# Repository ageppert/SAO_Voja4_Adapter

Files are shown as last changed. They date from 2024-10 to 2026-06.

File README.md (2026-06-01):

# SAO VOJA4 BADGE ADAPTER

Hardware add-on to enable Voja4 to speak I2C with a full-featured 6-pin SAO socket.

Maybe even SPI!

Follow this project at: https://hackaday.io/project/198394-sao-adapter-for-voja4-badge

Hardware Version 1.0 Prototype

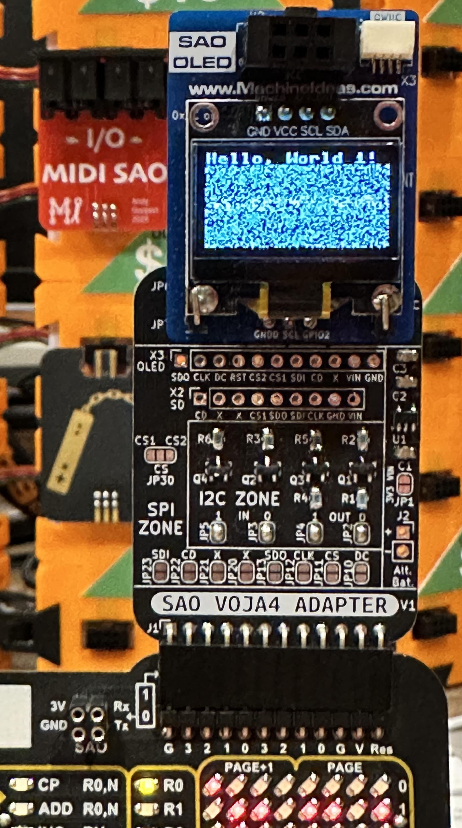
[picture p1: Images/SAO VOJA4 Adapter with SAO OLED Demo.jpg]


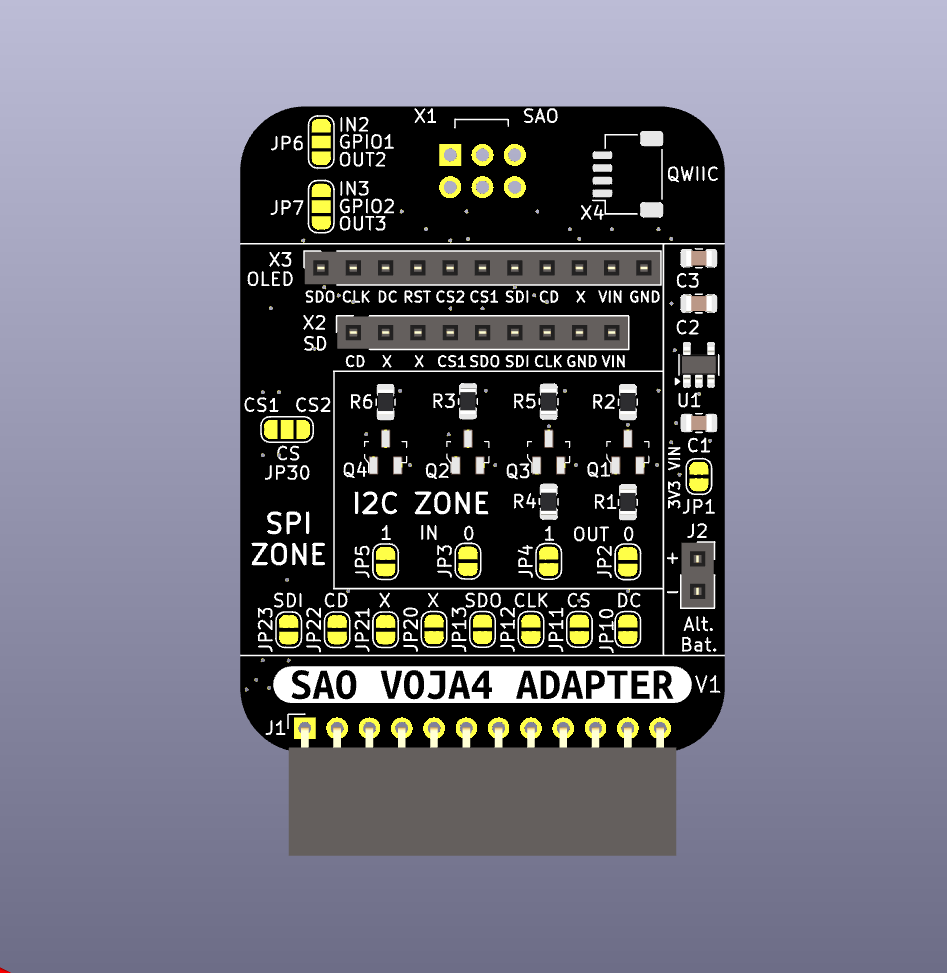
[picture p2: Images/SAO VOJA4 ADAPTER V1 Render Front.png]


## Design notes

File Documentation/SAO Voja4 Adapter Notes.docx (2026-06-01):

SAO Voja4 Adapter Notes V1.0

Kit Components

REF. DES. | DESCRIPTION | COMPONENT
C1, C3 | Capacitor, 1uF
C2 | Capacitor, 0.01uF
J1 | BYOB Battery 2.5-5.5 V
J2 | 0.1 inch female edge connect, 12-position
Q1-4 | Transistor, NPN, MMBT4401LT1G
R1, R4 | Resistor, 0805, 470 Ohm
R2,R3,R5,R6 | Resistor, 0805, 3K3 Ohm
U1 | LDO Regulator 3V3, SSP9193-33MSR
X1 | SAO Socket, Sullins SFH11-NBPC-D03-ST-BK, female, keyed
X2 | Any 0.1 inch pitch female header, 9-pin
X3 | Any 0.1 inch pitch female header, 11-pin
X4 | QWIIC Socket, 4-pos, male, keyed

Configuration Table

FEATURE | JP1 | JP2,4 | JP3,5 | JP6,7 | Q4 | JP10-13 | JP20-21 | JP22-23 | JP30 | Blue Wire Q4 Base to JP30 pad 3
I2C | ~ | Close | Close | ~ | In | Open | ~ | Open | Open | ~
SPI, Single | ~ | ~ | Open | Open | ~ | Close | ~ | Close | Close 1-2 | ~
SPI, Double * | ~ | Close | Open | Open | Out | Close | ~ | Close | Close 1-2 | Close
Alternate Power ** | Close | ~ | ~ | ~ | ~ | ~ | ~ | ~ | ~ | ~

* Dual SPI mode uses a single OUT1 line to toggle both CS1 and CS2 lines, with opposite logic.

OUT1 | CS1 | CS2
LOW | LOW | LOW
HIGH | HIGH | HIGH

** If using Alternate Power, limit alternate power voltage between 2.5 and 5.5V, and remove the batteries from the Voja4 Badge. This feature may be used with any of the other configuration features.

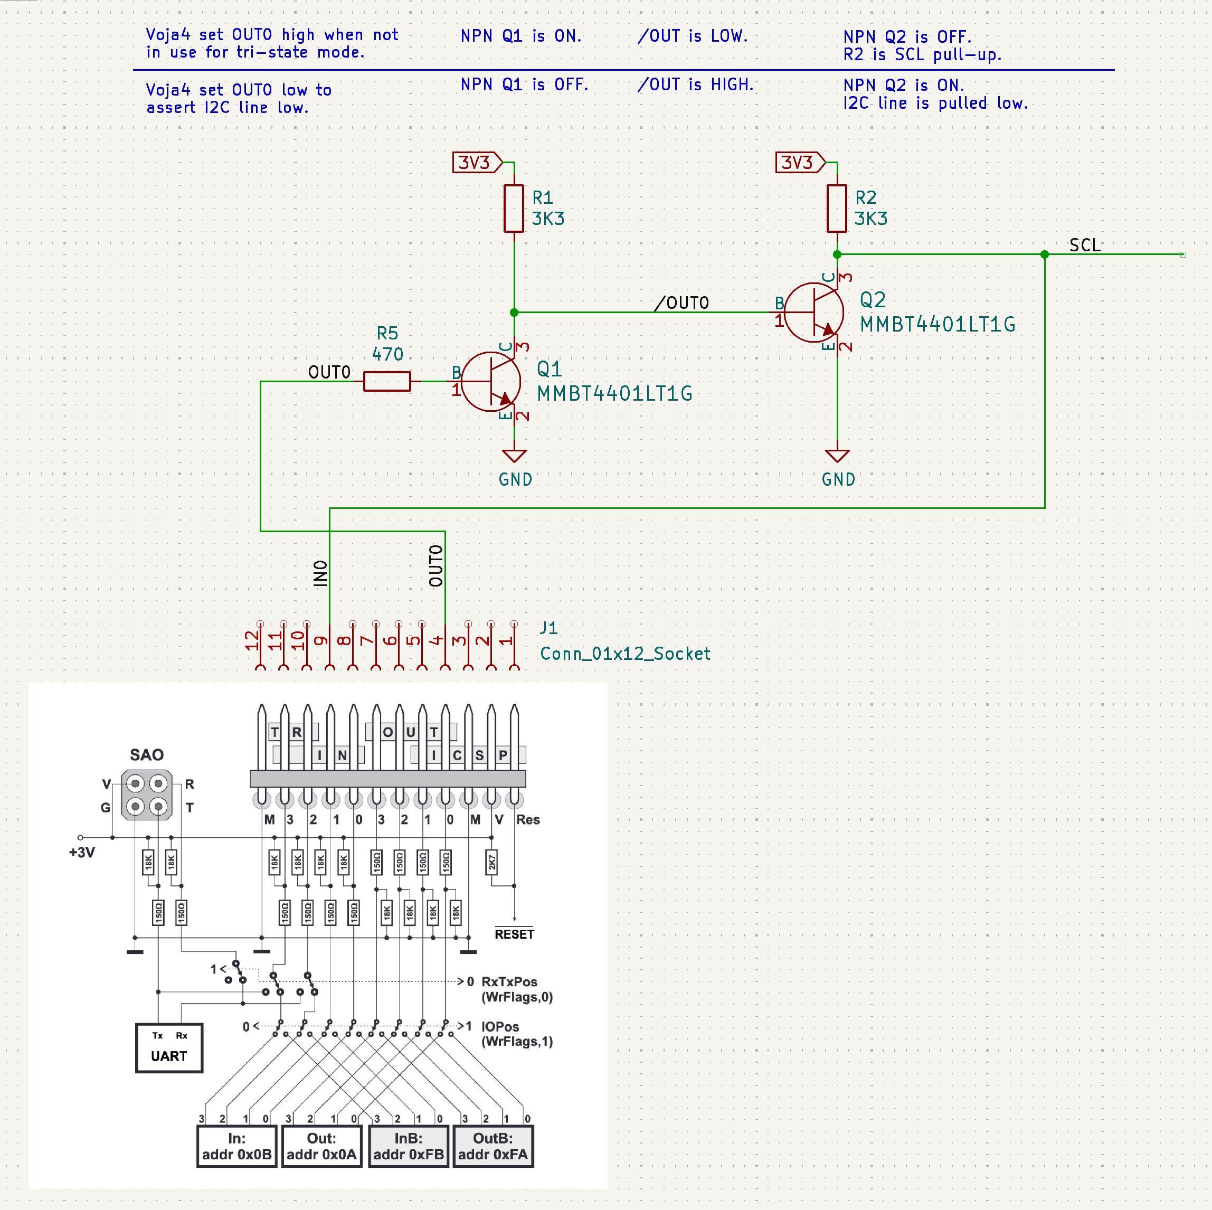
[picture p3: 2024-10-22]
Images/Schematic concept double NOT.png

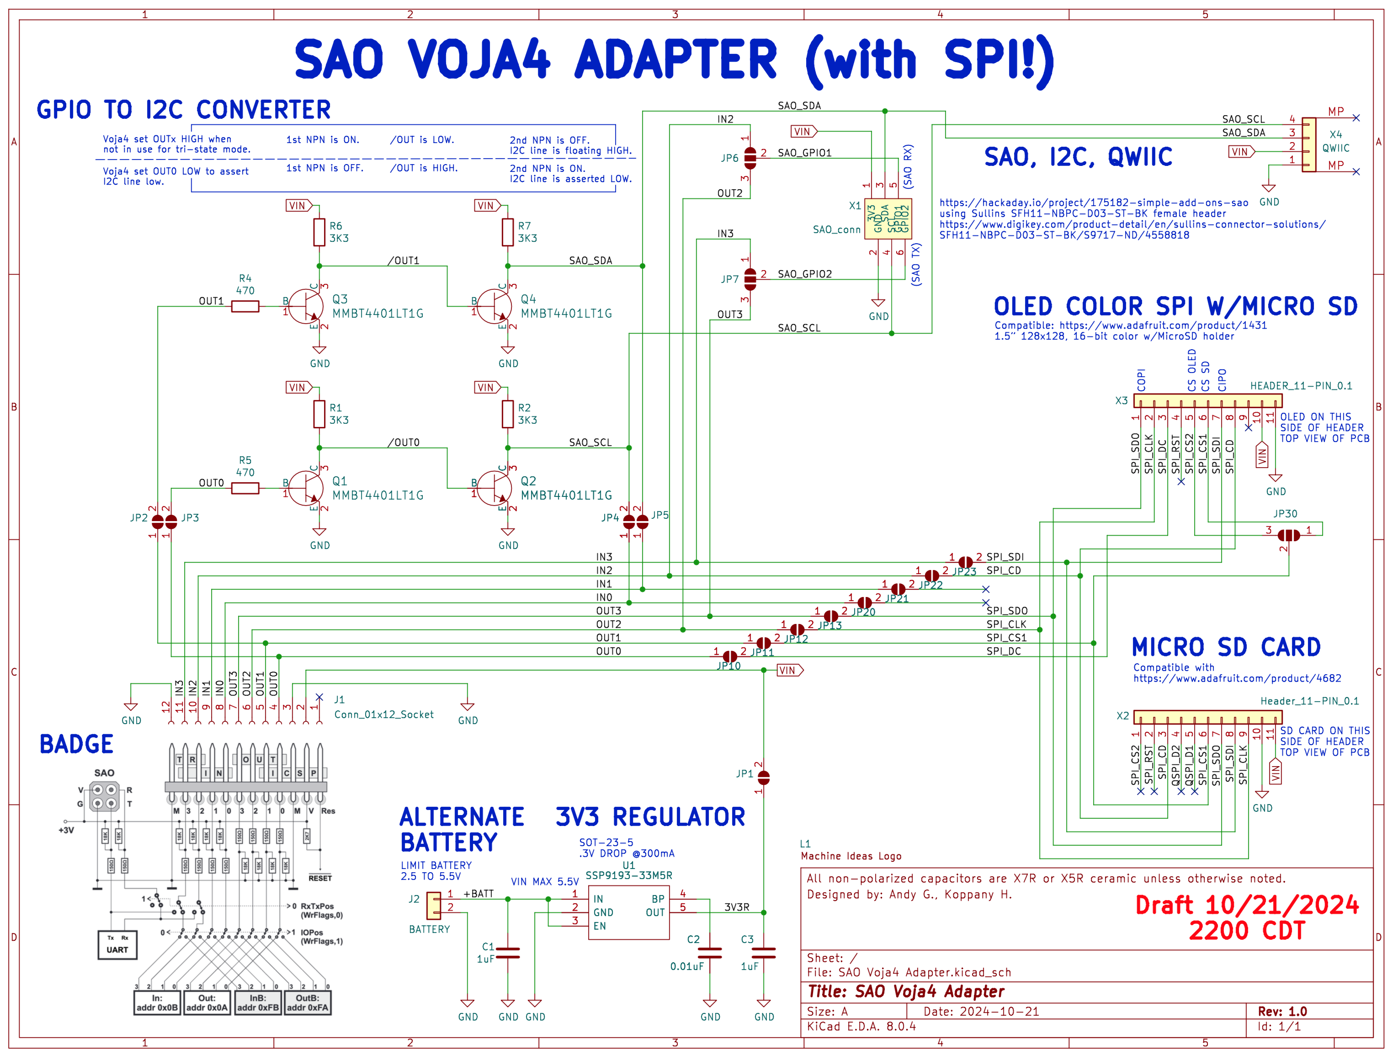
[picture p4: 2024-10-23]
Images/Schematic V1 draft 10-21-2024.png

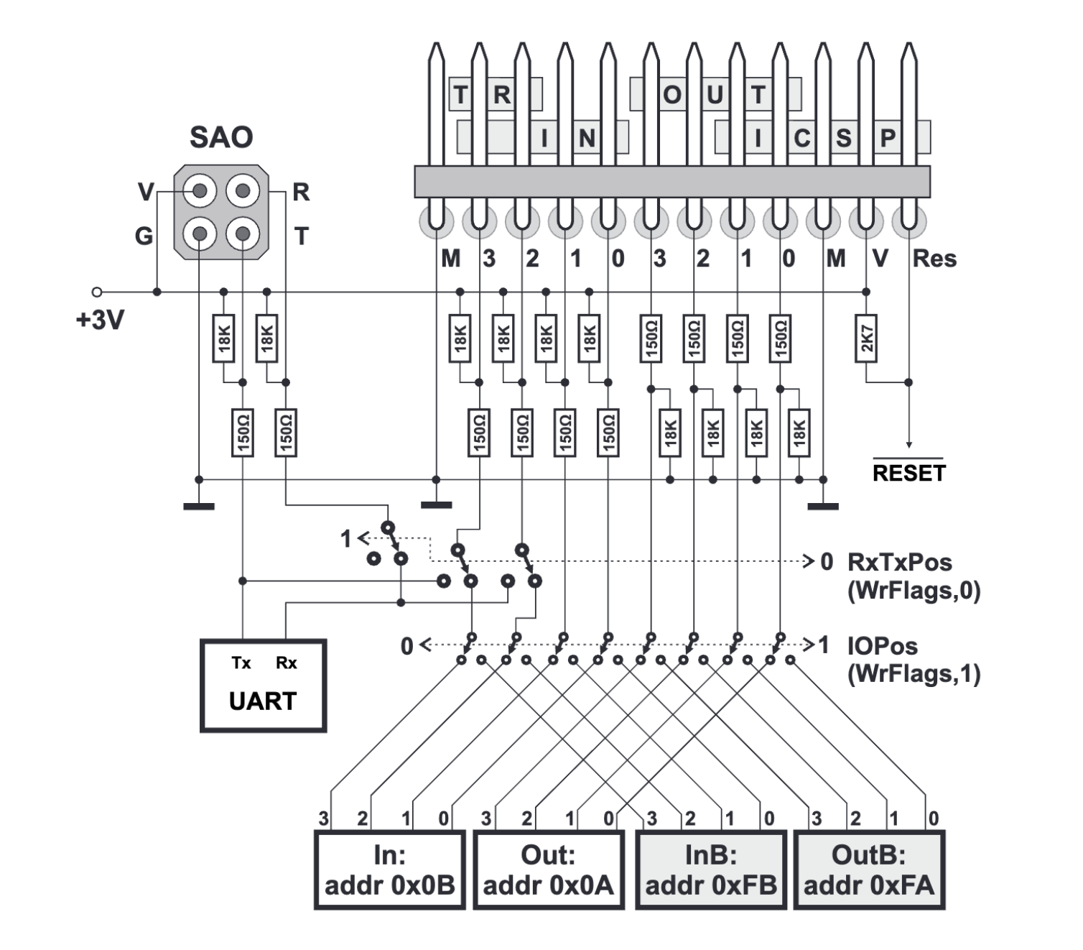
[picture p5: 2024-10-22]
Images/Voja4 IO Ports.png

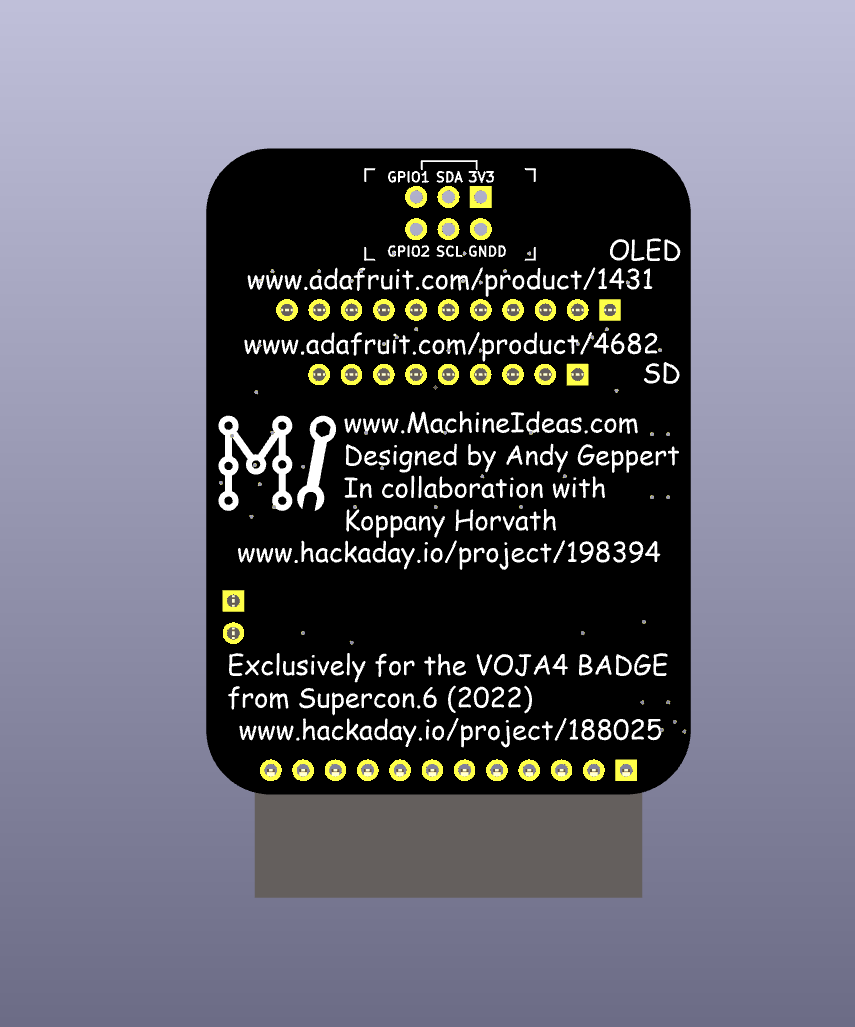
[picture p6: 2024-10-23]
Images/SAO VOJA4 ADAPTER V1 Render Back.png

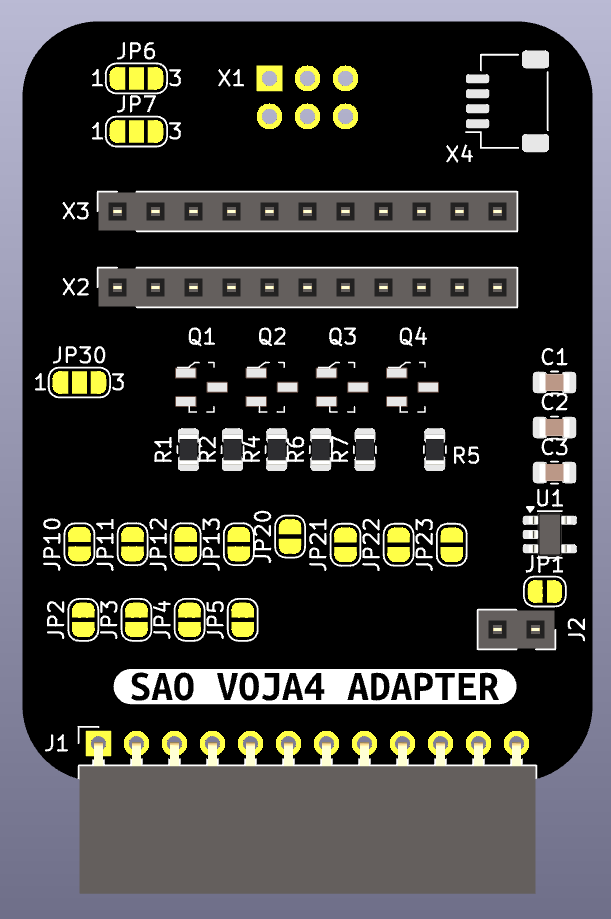
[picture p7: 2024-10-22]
Images/SAO VOJA4 ADAPTER RENDER FRONT draft.png

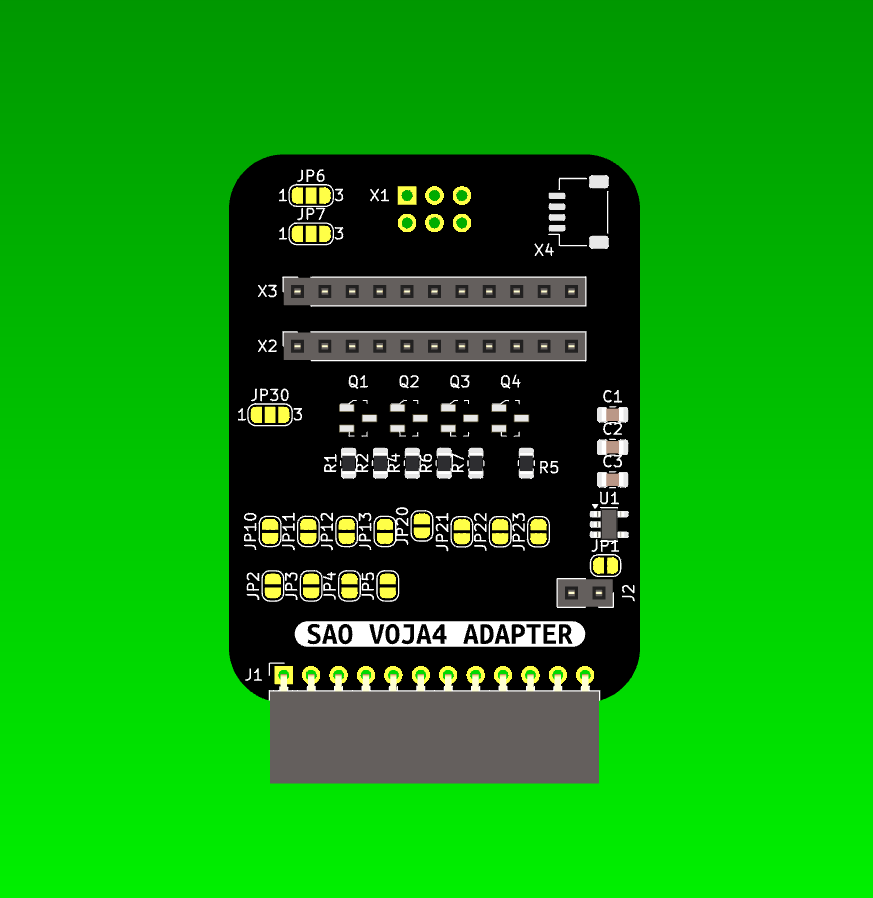
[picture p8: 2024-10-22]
Images/SAO VOJA4 ADAPTER RENDER FRONT 2 Kryptonite.png

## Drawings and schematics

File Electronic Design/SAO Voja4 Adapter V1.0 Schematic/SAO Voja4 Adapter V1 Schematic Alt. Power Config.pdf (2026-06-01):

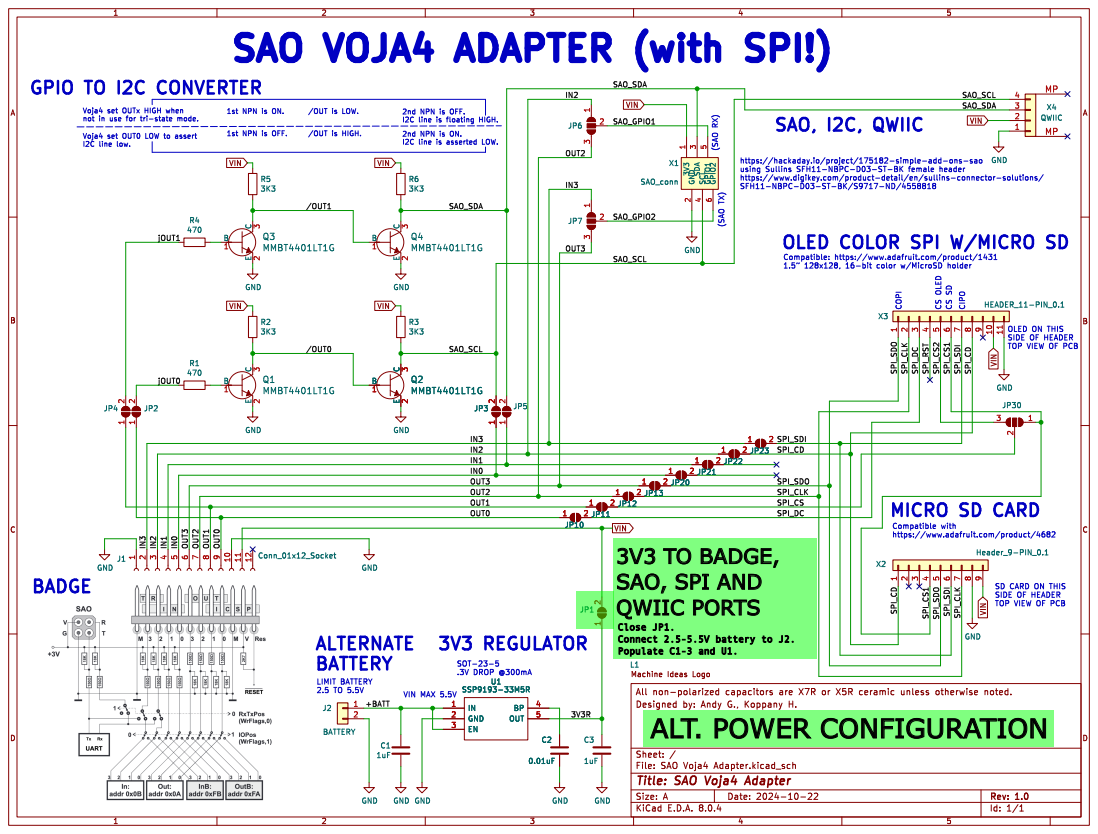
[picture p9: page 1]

3V3 TO BADGE,
SAO, SPI AND
QWIIC PORTS

Close JP1.
Connect 2.5-5.5V battery to J2.
Populate C1-3 and U1.

ALT. POWER CONFIGURATION

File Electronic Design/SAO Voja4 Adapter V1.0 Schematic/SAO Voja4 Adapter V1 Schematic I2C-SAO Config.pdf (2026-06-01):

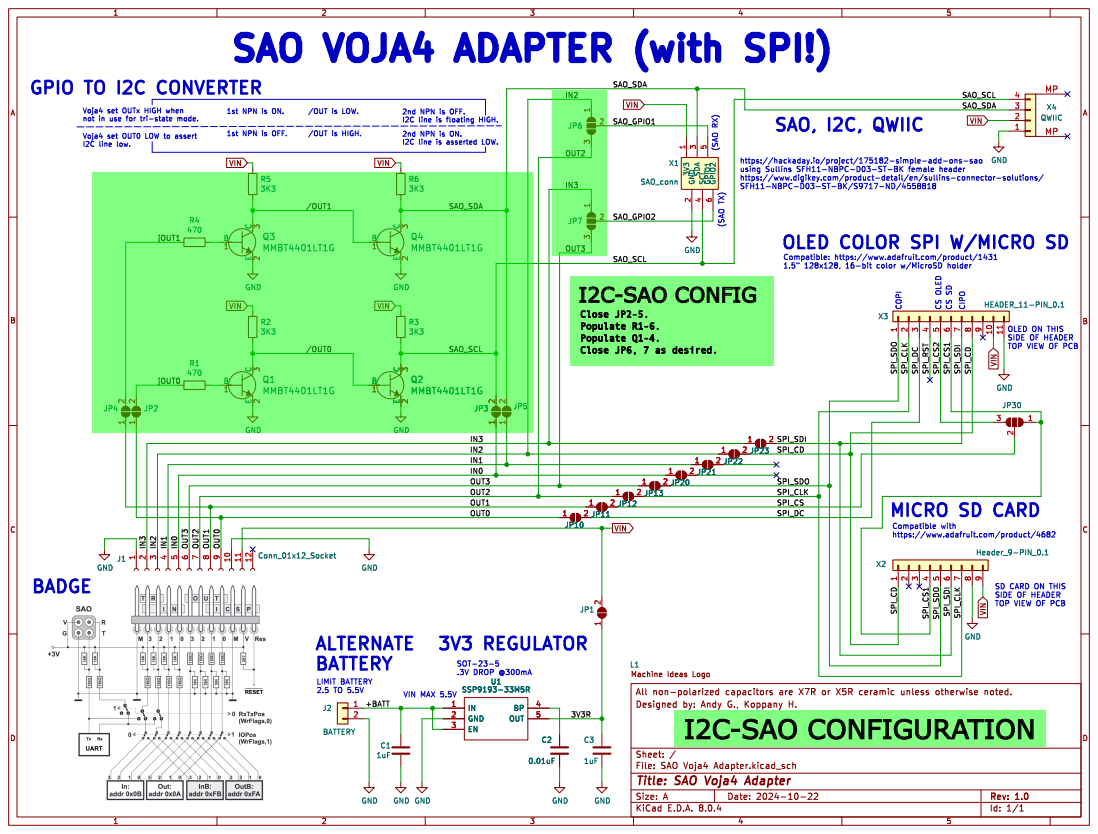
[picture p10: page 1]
I2C-SAO CONFIGURATION; I2C-SAO CONFIG

Close JP2-5.
Populate R1-6.
Populate Q1-4.
Close JP6, 7 as desired.

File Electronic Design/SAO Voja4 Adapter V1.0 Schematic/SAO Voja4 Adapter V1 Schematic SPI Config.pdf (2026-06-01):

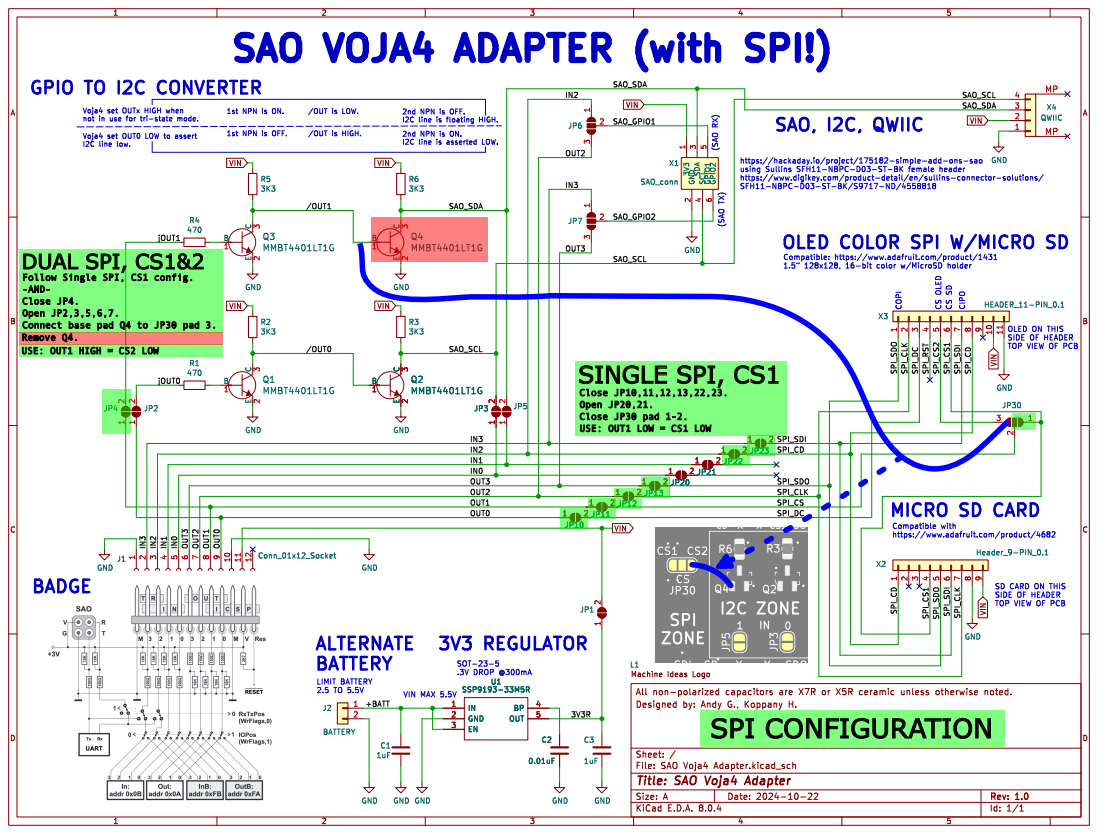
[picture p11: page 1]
SPI CONFIGURATION; SINGLE SPI, CS1

DUAL SPI, CS1&2 Follow Single SPI, CS1 config.

-AND-
Close JP4.
Open JP2,3,5,6,7.
Connect base pad Q4 to JP30 pad 3.
Remove Q4.
USE: OUT1 HIGH = CS2 LOW

Close JP10,11,12,13,22,23.
Open JP20,21.
Close JP30 pad 1-2.
USE: OUT1 LOW = CS1 LOW

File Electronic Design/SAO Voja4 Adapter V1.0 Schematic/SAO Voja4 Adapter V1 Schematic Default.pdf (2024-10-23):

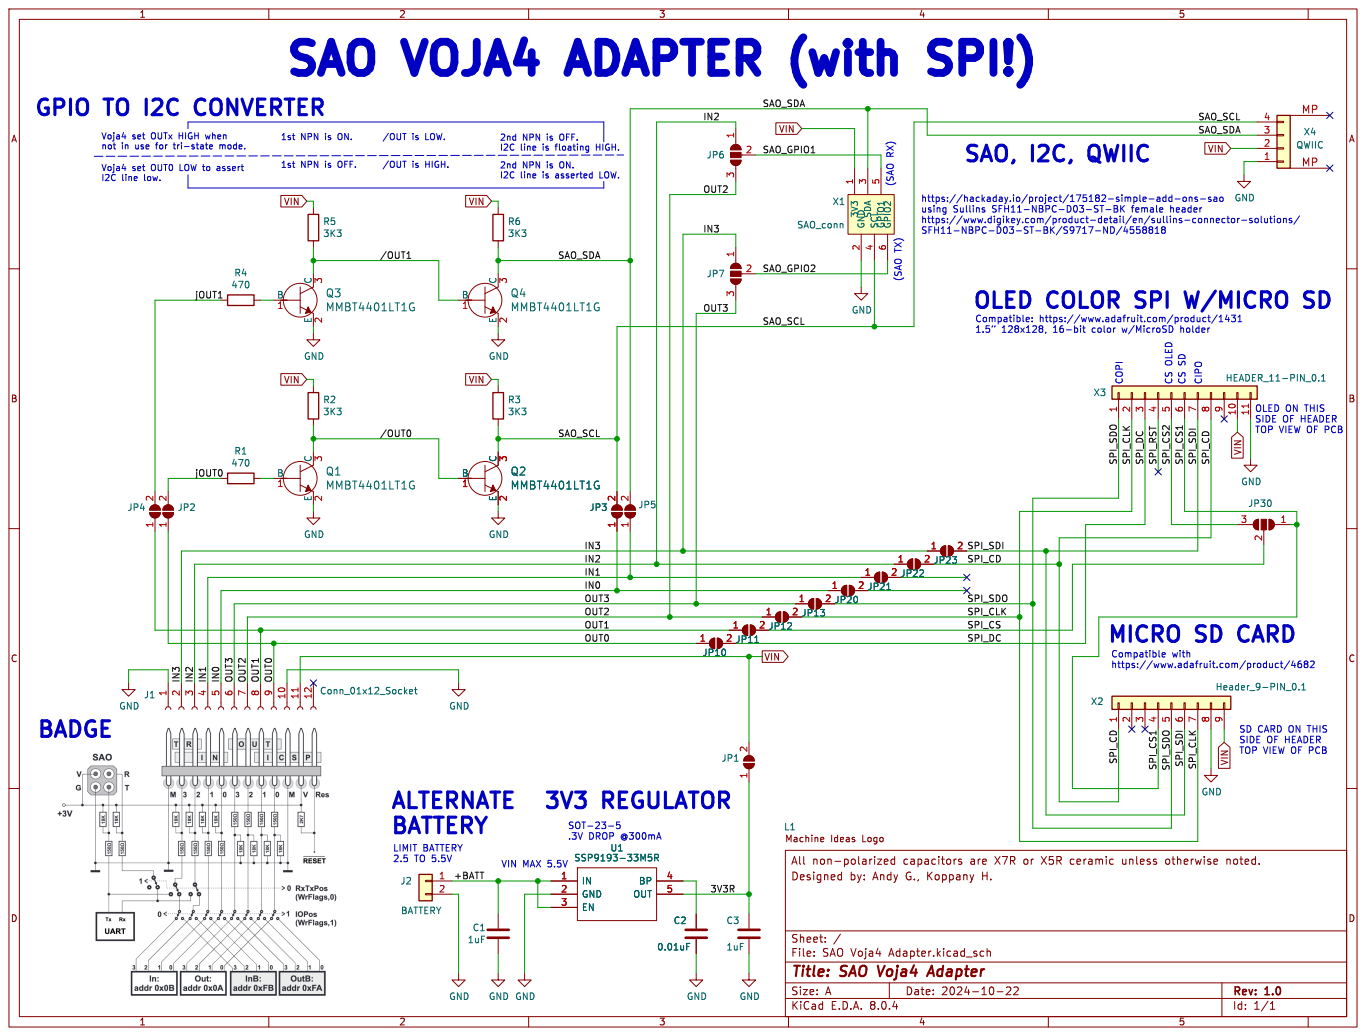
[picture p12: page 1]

SAO VOJA4 ADAPTER (with SPI!)

Voja4 set OUTx HIGH when

I2C line is asserted LOW. Voja4 set OUT0 LOW to assert
I2C line low.

https://hackaday.io/project/175182-simple-add-ons-sao

TOP VIEW OF PCB CIPO (SAO TX)

https://www.adafruit.com/product/4682

TOP VIEW OF PCB BADGE

SD CARD ON THIS
SIDE OF HEADER

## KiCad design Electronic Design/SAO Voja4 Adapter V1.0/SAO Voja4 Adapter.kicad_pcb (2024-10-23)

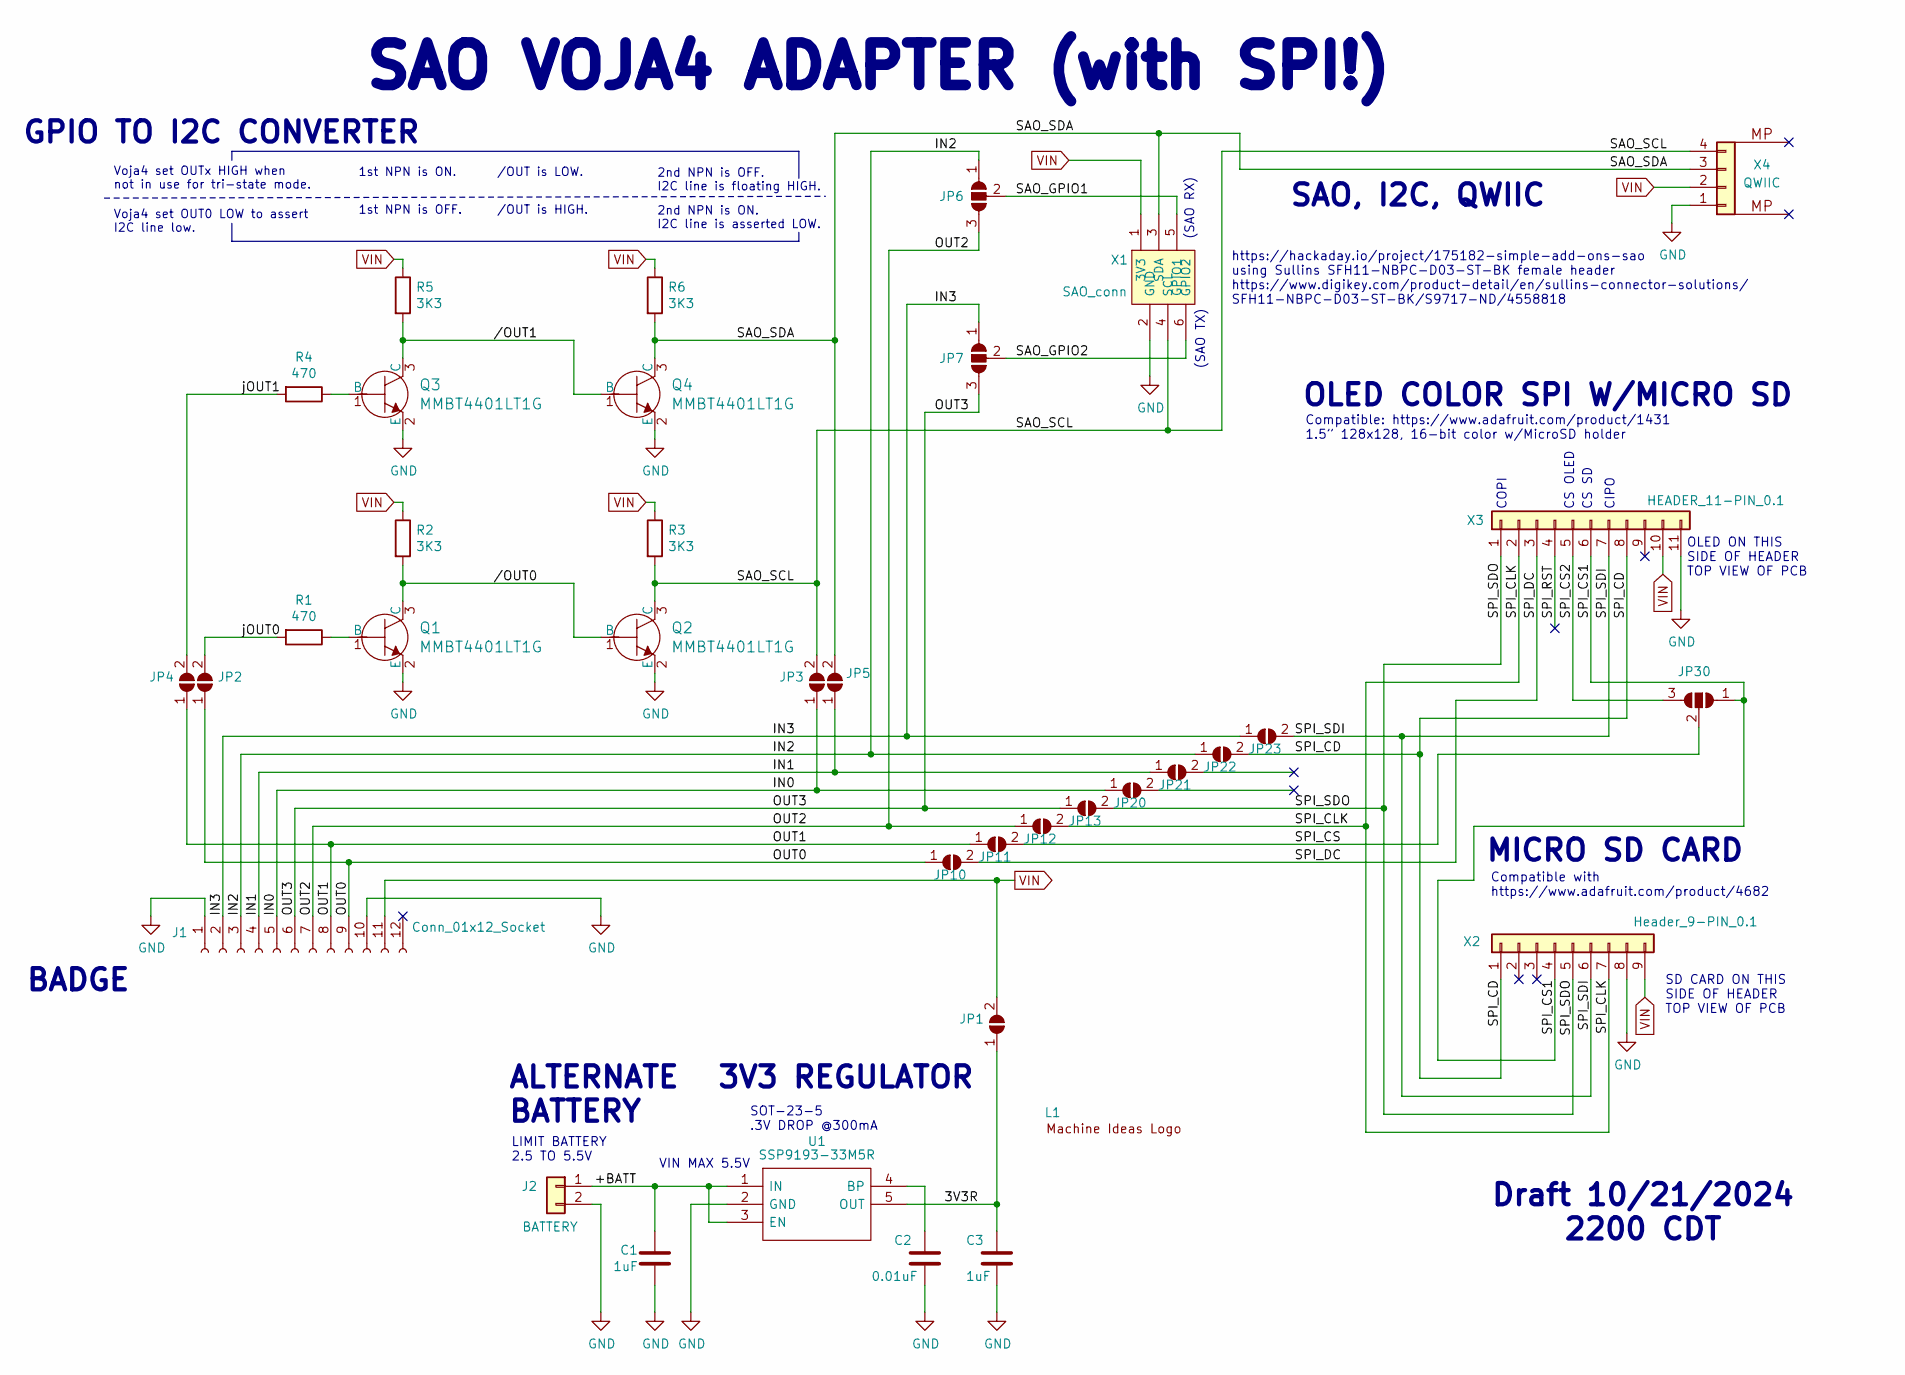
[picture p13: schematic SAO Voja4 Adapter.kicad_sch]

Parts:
C1, C3: 1uF; C_0805_2012Metric; LCSC C28323
C2: 0.01uF; C_0805_2012Metric; LCSC C1710
J1: Conn_01x12_Socket; PinSocket_1x12_P2.54mm_Horizontal
J2: BATTERY; PinSocket_1x02_P2.54mm_Vertical
JP1: VSEL; SolderJumper-2_P1.3mm_Open_RoundedPad1.0x1.5mm
JP2, JP3, JP4, JP5, JP10, JP11, JP12, JP13, JP20, JP21, JP22, JP23: JP; SolderJumper-2_P1.3mm_Open_RoundedPad1.0x1.5mm
JP6, JP7, JP30: SolderJumper_3_Open; SolderJumper-3_P1.3mm_Open_RoundedPad1.0x1.5mm_NumberLabels
L1: Machine_Ideas_logo
Q1, Q2, Q3, Q4: MMBT4401LT1G; SOT-23-3; MPN MMBT4401LT1G; Digi-Key_PN MMBT4401LT1GOSCT-ND
R1, R4: 470; R_0805_2012Metric; LCSC C17710
R2, R3, R5, R6: 3K3; R_0805_2012Metric; LCSC C17398
U1: SSP9193-33M5R; SOT-23-5; Manufacturer_Part_Number SGM2007-3.3XN5/TR; Mouser Part Number SGM2007-3.3XN5/TR
X1: SAO_conn; Badgelife-SAOv169-BADGE-2x3-no-front-text; MPN SFH11-NBPC-D03-ST-BK
X2: Header_9-PIN_0.1; PinSocket_1x09_P2.54mm_Vertical
X3: HEADER_11-PIN_0.1; PinSocket_1x11_P2.54mm_Vertical
X4: QWIIC; JST_SH_SM04B-SRSS-TB_1x04-1MP_P1.00mm_Horizontal; MPN SM04B-SRSS-TB; LCSC C160404

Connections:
/3V3R: C3.1, JP1.1 (A), U1.5 (OUT)
/+BATT: C1.1, J2.1, U1.1 (IN), U1.3 (EN)
/IN0: J1.5, JP3.1 (A), JP20.1 (A)
/IN1: J1.4, JP5.1 (A), JP21.1 (A)
/IN2: J1.3, JP6.1 (A), JP22.1 (A)
/IN3: J1.2, JP7.1 (A), JP23.1 (A)
/OUT0: J1.9, JP2.1 (A), JP10.1 (A)
/OUT1: J1.8, JP4.1 (A), JP11.1 (A)
/OUT2: J1.7, JP6.3 (B), JP12.1 (A)
/OUT3: J1.6, JP7.3 (B), JP13.1 (A)
/SAO_GPIO1: JP6.2 (C), X1.5 (GPIO1)
/SAO_GPIO2: JP7.2 (C), X1.6 (GPIO2)
/SAO_SCL: JP3.2 (B), Q2.3 (C), R3.2, X1.4 (SCL), X4.4
/SAO_SDA: JP5.2 (B), Q4.3 (C), R6.2, X1.3 (SDA), X4.3
/SPI_CD: JP22.2 (B), X2.1, X3.8
/SPI_CLK: JP12.2 (B), X2.7, X3.2
/SPI_CS: JP11.2 (B), JP30.2 (C)
/SPI_CS1: JP30.1 (A), X2.4, X3.6
/SPI_CS2: JP30.3 (B), X3.5
/SPI_DC: JP10.2 (B), X3.3
/SPI_RST: X3.4
/SPI_SDI: JP23.2 (B), X2.6, X3.7
/SPI_SDO: JP13.2 (B), X2.5, X3.1
/jOUT0: JP2.2 (B), R1.2
/jOUT1: JP4.2 (B), R4.2
//OUT0: Q1.3 (C), Q2.1 (B), R2.2
//OUT1: Q3.3 (C), Q4.1 (B), R5.2
GND: C1.2, C2.2, C3.2, J1.1, J1.10, J2.2, Q1.2 (E), Q2.2 (E), Q3.2 (E), Q4.2 (E), U1.2 (GND), X1.2 (GND), X2.8, X3.11, X4.1
unnamed: Q1.1 (B), R1.1
unnamed: Q3.1 (B), R4.1
unnamed: C2.1, U1.4 (BP)
VIN: J1.11, JP1.2 (B), R2.1, R3.1, R5.1, R6.1, X1.1 (3V3), X2.9, X3.10, X4.2

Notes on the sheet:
https://hackaday.io/project/175182-simple-add-ons-sao using Sullins SFH11-NBPC-D03-ST-BK female header https://www.digikey.com/product-detail/en/sullins-connector-solutions/ SFH11-NBPC-D03-ST-BK/S9717-ND/4558818
COPI
CS SD
2nd NPN is ON. I2C line is asserted LOW.
Draft 10/21/2024 2200 CDT
3V3 REGULATOR
Compatible with https://www.adafruit.com/product/4682
GPIO TO I2C CONVERTER
Voja4 set OUTx HIGH when not in use for tri-state mode.
SAO VOJA4 ADAPTER (with SPI!)
CS OLED
Voja4 set OUT0 LOW to assert I2C line low.
MICRO SD CARD
SOT-23-5 .3V DROP @300mA
OLED ON THIS SIDE OF HEADER TOP VIEW OF PCB
2nd NPN is OFF. I2C line is floating HIGH.
Compatible: https://www.adafruit.com/product/1431 1.5” 128x128, 16-bit color w/MicroSD holder
ALTERNATE BATTERY
(SAO TX)
1st NPN is ON.
VIN MAX 5.5V
1st NPN is OFF.
BADGE
OLED COLOR SPI W/MICRO SD
SAO, I2C, QWIIC
SD CARD ON THIS SIDE OF HEADER TOP VIEW OF PCB
CIPO
/OUT is HIGH.
/OUT is LOW.
LIMIT BATTERY 2.5 TO 5.5V
(SAO RX)

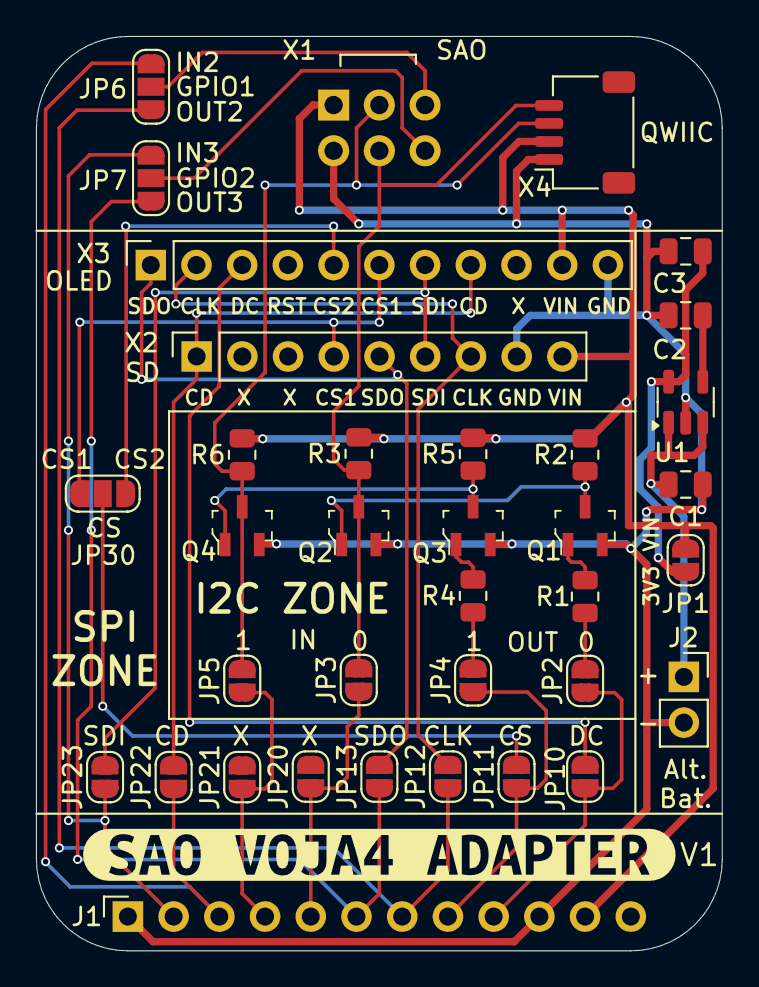
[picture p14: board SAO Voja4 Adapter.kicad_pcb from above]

Board: 2 copper layers, 38.1 x 50.8 mm, 38 parts (1 on the bottom side), 31 nets.

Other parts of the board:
kibuzzard-671724A5: G***; kibuzzard-671724A5

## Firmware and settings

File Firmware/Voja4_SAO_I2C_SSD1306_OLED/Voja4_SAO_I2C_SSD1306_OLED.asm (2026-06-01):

; Core4 Demo by koppanyh
; Created Nov 2024
; Designed to interface with the SAO Adapter for Voja4:
; https://hackaday.io/project/198394-sao-adapter-for-voja4-badge



;;;;;;;;;;;;;;;;;;;;;;;;;;;;
;;                        ;;
;;  Start of I2C Section  ;;
;;                        ;;
;;;;;;;;;;;;;;;;;;;;;;;;;;;;

; IO0 is SCL
; IO1 is SDA

; Example usage:
;GOSUB i2c_start      ; Trigger START condition
;MOV R4, 0x3          ; Send 0x3C address in write mode
;MOV R3, 0xC
;MOV R0, 0
;GOSUB i2c_send_addr
;MOV R3, 0b1000       ; Send 'H' character
;MOV R4, 0b0100
;GOSUB i2c_send_byte
;MOV R3, 0b0101       ; Send 'e' character
;MOV R4, 0b0110
;GOSUB i2c_send_byte
;MOV R3, 0b1100       ; Send 'l' character
;MOV R4, 0b0110
;GOSUB i2c_send_byte
;MOV R3, 0b1100       ; Send 'l' character
;MOV R4, 0b0110
;GOSUB i2c_send_byte
;MOV R3, 0b1111       ; Send 'o' character
;MOV R4, 0b0110
;GOSUB i2c_send_byte
;MOV R3, 0b0001       ; Send '!' character
;MOV R4, 0b0010
;GOSUB i2c_send_byte
;GOSUB i2c_stop       ; Trigger STOP condition 

; Init
; Set up the IO port and select which registers to control it with, then jump
; to main routine.
; Params: none
; Returns: none
; Modifies registers: R0, PCH, PCM, PCL
init:
MOV R0, 0x0  ; use IO on zero page registers and enable IO port
MOV [0xF3], R0
GOTO main
; signature "koppanyh" (view in hex editor)
MOV PC, [0x6:0xB]
MOV PC, [0x6:0xF]
MOV PC, [0x7:0x0]
MOV PC, [0x7:0x0]
MOV PC, [0x6:0x1]
MOV PC, [0x6:0xE]
MOV PC, [0x7:0x9]
MOV PC, [0x6:0x8]

; I2C Stop
; Stop the I2C transmission. Also init the I2C bus the first time.
; Params: none
; Returns: none
; Modifies registers: R0, Out
i2c_stop:
MOV R0, Out
AND R0, 0b1110  ; scl = 0
MOV Out, R0
AND R0, 0b1101  ; sda = 0
MOV Out, R0
OR R0, 0b0001  ; scl = 1
MOV Out, R0
OR R0, 0b0010  ; sda = 1
MOV Out, R0
RET R0, 0

; I2C Start
; Start the I2C transmission.
; Params: none
; Returns: none
; Modifies registers: R0, Out
i2c_start:
MOV R0, Out
OR R0, 0b0001  ; scl = 1
MOV Out, R0
OR R0, 0b0010  ; sda = 1
MOV Out, R0
AND R0, 0b1101  ; sda = 0
MOV Out, R0
AND R0, 0b1110  ; scl = 0
MOV Out, R0
RET R0, 0

; I2C Send Nybble
; Send a single nybble on the I2C bus.
; Params:
;   R1: The nybble to send on the bus.
; Returns: none
; Modifies registers: R0, R1, R2, Out
i2c_send_nybble:
MOV R2, 4  ; set counter to 4
MOV R0, Out  ; copy Out's current state
; jump target: #0
AND R0, 0b1101  ; set virtual SDA to 0            <-+
BIT R1, 3  ; check nybble's high bit                |
SKIP Z, 1  ; set virtual SDA to 1 if it's not 0     |
OR R0, 0b0010  ;                                    |
MOV Out, R0  ; sda = virtual SDA                    |
ADD R1, R1  ; shift nybble left                     |
OR R0, 0b0001  ; scl = 1 (pulse the clock)          |
MOV Out, R0  ;                                      |
AND R0, 0b1110  ; scl = 0                           |
MOV Out, R0  ;                                      |
DSZ R2  ; dec counter and ret if 0                  |
JR -12  ; jump to #0, MAKE SURE THIS IS CORRECT!!! -+
RET R0, 0

; I2C Send Byte
; Send a single byte on the I2C bus.
; Params:
;   R3: The byte's low nybble to send on the bus.
;   R4: The byte's high nybble to send on the bus.
; Returns:
;   R0: The ack status on the bus (true is error).
; Modifies registers: R0, R1, R2, Out
i2c_send_byte:
MOV R1, R4  ; send high nybble
GOSUB i2c_send_nybble
MOV R1, R3  ; send low nybble
GOSUB i2c_send_nybble
MOV R0, Out
OR R0, 0b0010  ; sda = 1 (so the target can ack by pulling down)
MOV Out, R0
OR R0, 0b0001  ; scl = 1
MOV Out, R0
; TODO Implement clock stretching here
MOV R1, In  ; R1 = raw input containing ack status from sda
MOV R0, Out  ; scl = 0
AND R0, 0b1110
MOV Out, R0
BIT R1, 1  ; return (R1 & 0b0010) >> 1
SKIP Z, 1
RET R0, 1
RET R0, 0

; I2C Send Addr
; Send the address byte on the I2C bus.
; Params:
;   R0: Whether to read (1) or write (0).
;   R3: The low nybble of the address.
;   R4: The high nybble of the address.
; Returns:
;   R0: The ack status on the bus (true is error).
; Modifies registers: R0, R1, R2, R3, R4, Out
i2c_send_addr:
ADD R3, R3  ; addr <<= 1
ADC R4, R4
ADD R3, R0  ; addr |= readwritebit
GOSUB i2c_send_byte
CP R0, 0
SKIP Z, 1
RET R0, 1
RET R0, 0

;;;;;;;;;;;;;;;;;;;;;;;;;;
;;                      ;;
;;  End of I2C Section  ;;
;;                      ;;
;;;;;;;;;;;;;;;;;;;;;;;;;;



; Main
; Do the thing.
; Params: none
; Returns: none
; Registers: ?
main:
GOSUB i2c_start
MOV R3, 0xc
MOV R4, 0x3
MOV R0, 0
GOSUB i2c_send_addr
MOV R3, 0x0
MOV R4, 0x8
GOSUB i2c_send_byte
MOV R3, 0xe
MOV R4, 0xa
GOSUB i2c_send_byte
GOSUB i2c_stop

GOSUB i2c_start
MOV R3, 0xc
MOV R4, 0x3
MOV R0, 0
GOSUB i2c_send_addr
MOV R3, 0x0
MOV R4, 0x8
GOSUB i2c_send_byte
MOV R3, 0x0
MOV R4, 0x2
GOSUB i2c_send_byte
GOSUB i2c_stop

GOSUB i2c_start
MOV R3, 0xc
MOV R4, 0x3
MOV R0, 0
GOSUB i2c_send_addr
MOV R3, 0x0
MOV R4, 0x8
GOSUB i2c_send_byte
MOV R3, 0x0
MOV R4, 0x0
GOSUB i2c_send_byte
GOSUB i2c_stop

GOSUB i2c_start
MOV R3, 0xc
MOV R4, 0x3
MOV R0, 0
GOSUB i2c_send_addr
MOV R3, 0x0
MOV R4, 0x8
GOSUB i2c_send_byte
MOV R3, 0x0
MOV R4, 0x4
GOSUB i2c_send_byte
GOSUB i2c_stop

GOSUB i2c_start
MOV R3, 0xc
MOV R4, 0x3
MOV R0, 0
GOSUB i2c_send_addr
MOV R3, 0x0
MOV R4, 0x8
GOSUB i2c_send_byte
MOV R3, 0x1
MOV R4, 0xa
GOSUB i2c_send_byte
GOSUB i2c_stop

GOSUB i2c_start
MOV R3, 0xc
MOV R4, 0x3
MOV R0, 0
GOSUB i2c_send_addr
MOV R3, 0x0
MOV R4, 0x8
GOSUB i2c_send_byte
MOV R3, 0x8
MOV R4, 0xa
GOSUB i2c_send_byte
GOSUB i2c_stop

GOSUB i2c_start
MOV R3, 0xc
MOV R4, 0x3
MOV R0, 0
GOSUB i2c_send_addr
MOV R3, 0x0
MOV R4, 0x8
GOSUB i2c_send_byte
MOV R3, 0xf
MOV R4, 0x3
GOSUB i2c_send_byte
GOSUB i2c_stop

GOSUB i2c_start
MOV R3, 0xc
MOV R4, 0x3
MOV R0, 0
GOSUB i2c_send_addr
MOV R3, 0x0
MOV R4, 0x8
GOSUB i2c_send_byte
MOV R3, 0x8
MOV R4, 0xc
GOSUB i2c_send_byte
GOSUB i2c_stop

GOSUB i2c_start
MOV R3, 0xc
MOV R4, 0x3
MOV R0, 0
GOSUB i2c_send_addr
MOV R3, 0x0
MOV R4, 0x8
GOSUB i2c_send_byte
MOV R3, 0x3
MOV R4, 0xd
GOSUB i2c_send_byte
GOSUB i2c_stop

GOSUB i2c_start
MOV R3, 0xc
MOV R4, 0x3
MOV R0, 0
GOSUB i2c_send_addr
MOV R3, 0x0
MOV R4, 0x8
GOSUB i2c_send_byte
MOV R3, 0x0
MOV R4, 0x0
GOSUB i2c_send_byte
GOSUB i2c_stop

GOSUB i2c_start
MOV R3, 0xc
MOV R4, 0x3
MOV R0, 0
GOSUB i2c_send_addr
MOV R3, 0x0
MOV R4, 0x8
GOSUB i2c_send_byte
MOV R3, 0xa
MOV R4, 0xd
GOSUB i2c_send_byte
GOSUB i2c_stop

GOSUB i2c_start
MOV R3, 0xc
MOV R4, 0x3
MOV R0, 0
GOSUB i2c_send_addr
MOV R3, 0x0
MOV R4, 0x8
GOSUB i2c_send_byte
MOV R3, 0x2
MOV R4, 0x1
GOSUB i2c_send_byte
GOSUB i2c_stop

GOSUB i2c_start
MOV R3, 0xc
MOV R4, 0x3
MOV R0, 0
GOSUB i2c_send_addr
MOV R3, 0x0
MOV R4, 0x8
GOSUB i2c_send_byte
MOV R3, 0x5
MOV R4, 0xd
GOSUB i2c_send_byte
GOSUB i2c_stop

GOSUB i2c_start
MOV R3, 0xc
MOV R4, 0x3
MOV R0, 0
GOSUB i2c_send_addr
MOV R3, 0x0
MOV R4, 0x8
GOSUB i2c_send_byte
MOV R3, 0x0
MOV R4, 0x8
GOSUB i2c_send_byte
GOSUB i2c_stop
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

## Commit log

2024-10-22 First draft
    FIRST DRAFT FOR REVIEW!!!
    [SAO Voja4 Adapter.kicad_pcb, SAO Voja4 Adapter.kicad_sch]
2024-10-23 Released V1 boards
    [SAO Voja4 Adapter.kicad_pcb, SAO Voja4 Adapter.kicad_sch]
2024-10-23 Remove draft V1 schematic
    [SAO Voja4 Adapter.kicad_sch]
2024-10-23 And SPI
2024-10-23 Add BOM items in KiCAD schematic
    [SAO Voja4 Adapter.kicad_sch]
2026-06-01 Add documentation notes and schematic configs
